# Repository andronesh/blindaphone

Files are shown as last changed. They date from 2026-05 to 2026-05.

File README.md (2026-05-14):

## ESP32-C3-Supermini wiring

| INMP441 | ESP32 |
| :-----: | :---: |
| GND |  GND  |
| VDD |  3v3  |
| SD | GPIO6 |
| LR |  GND  |
| WS | GPIO5 |
| SCK | GPIO4 |

| MAX98357A | ESP32 |
| :---: | :---: |
| LRC | GPIO5 |
| BCLK | GPIO4 |
| DIN | GPIO7 |
| GAIN | - |
| SD | - |
| GND |  GND  |
| VIN |  5v |

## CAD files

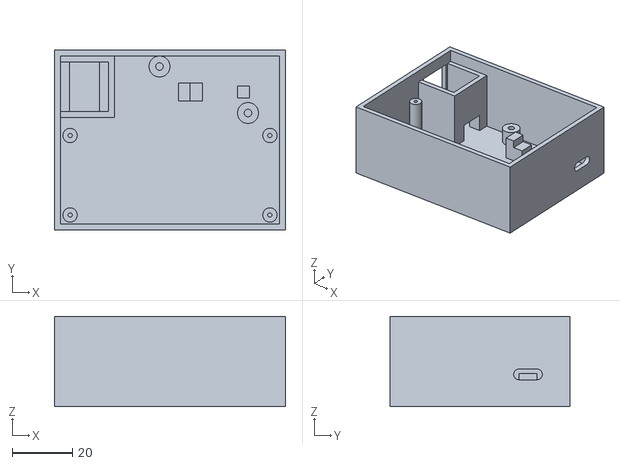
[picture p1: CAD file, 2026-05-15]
case_files/blindaphone box v2 bottom.stl
77.0 x 60.0 x 30.0

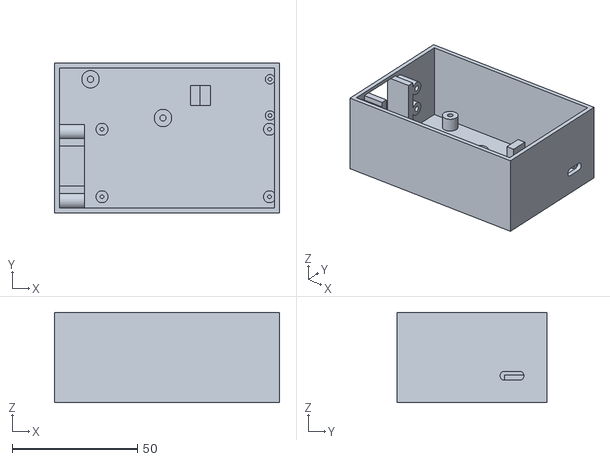
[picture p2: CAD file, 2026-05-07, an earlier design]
case_files/blindaphone box v1 bottom.stl
90.0 x 60.0 x 36.0

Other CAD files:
case_files/blindaphone box v1 bottom.f3d
case_files/blindaphone box v2 bottom.f3d

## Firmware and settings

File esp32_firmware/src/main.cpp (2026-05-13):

#include <Arduino.h>
#include "driver/i2s.h"
#include <math.h>
#include "Button.h"

#define I2S_PORT I2S_NUM_0

#define I2S_BCLK 4
#define I2S_LRCK 5
#define I2S_DIN  6   // mic
#define I2S_DOUT 7   // amp

const gpio_num_t REC_BTN_PIN = GPIO_NUM_9;

#define RX_PIN 20
#define TX_PIN 21
#define DIR_PIN 10
const gpio_num_t CMD_BTN_PIN = GPIO_NUM_3;

#define LED_PIN GPIO_NUM_2
bool isLedOn = false;

HardwareSerial RS485(1);

#define SAMPLE_RATE 16000
#define AUDIO_BLOCK_SAMPLES 128

volatile bool isTalking = false;
bool ignoreFirstPacket = true;

int32_t i2sInBuffer[AUDIO_BLOCK_SAMPLES];
int32_t i2sOutBuffer[AUDIO_BLOCK_SAMPLES];

int16_t uartBuffer[AUDIO_BLOCK_SAMPLES];

float GAIN = 15.0;

void setupI2S() {
    i2s_config_t config = {
        .mode = (i2s_mode_t)(I2S_MODE_MASTER | I2S_MODE_TX | I2S_MODE_RX),
        .sample_rate = SAMPLE_RATE,
        .bits_per_sample = I2S_BITS_PER_SAMPLE_32BIT,
        .channel_format = I2S_CHANNEL_FMT_ONLY_LEFT,
        .communication_format = I2S_COMM_FORMAT_I2S,
        .intr_alloc_flags = 0,
        .dma_buf_count = 8,
        .dma_buf_len = 128,
        .use_apll = false
    };

    i2s_pin_config_t pins = {
        .bck_io_num = I2S_BCLK,
        .ws_io_num = I2S_LRCK,
        .data_out_num = I2S_DOUT,
        .data_in_num = I2S_DIN
    };

    i2s_driver_install(I2S_PORT, &config, 0, NULL);
    i2s_set_pin(I2S_PORT, &pins);
}

void setTransmitMode() {
    digitalWrite(DIR_PIN, HIGH);
    // Serial.println("TX MODE");
    delayMicroseconds(50);
}

void setReceiveMode() {
    ignoreFirstPacket = true;
    delayMicroseconds(50);
    digitalWrite(DIR_PIN, LOW);
    // Serial.println("RX MODE");
    delayMicroseconds(50);
}

void sendMessage(const char* msg) {
    Serial.println("--- sending: " + String(msg));
    setTransmitMode();

    RS485.print(msg);
    RS485.flush();

    delayMicroseconds(10);
    setReceiveMode();
}

static void onCommandButtonPressDownCb(void *button_handle, void *usr_data) {
    Serial.println("--- CMD BTN DOWN ...");
    sendMessage("button pressed\n");
}

static void onRecordingButtonPressDownCb(void *button_handle, void *usr_data) {
    RS485.flush();

    while (RS485.available()) {
        RS485.read();
    }

    delay(20);

    setTransmitMode();
    isTalking = true;

    digitalWrite(LED_PIN, HIGH);
}

static void onRecordingButtonPressUpCb(void *button_handle, void *usr_data) {
    isTalking = false;

    RS485.flush();
    delay(20);
    setReceiveMode();

    while (RS485.available()) {
        RS485.read();
    }

    digitalWrite(LED_PIN, LOW);
}

void initButtons() {
    Button *btnCmd = new Button(CMD_BTN_PIN, false);
    btnCmd->attachPressDownEventCb(&onCommandButtonPressDownCb, NULL);

    Button *btnRec = new Button(REC_BTN_PIN, false);
    btnRec->attachPressDownEventCb(&onRecordingButtonPressDownCb, NULL);
    btnRec->attachPressUpEventCb(&onRecordingButtonPressUpCb, NULL);
}

void initRS485() {
    pinMode(DIR_PIN, OUTPUT);
    setReceiveMode();

    Serial.begin(115200);
    RS485.begin(1000000, SERIAL_8N1, RX_PIN, TX_PIN);

    RS485.setRxBufferSize(4096);
    RS485.setTxBufferSize(4096);
}

// void startRecordingSession() {
//     Serial.println("Recording...");
//     inRecordingSession = true;
//     recordedSamples = 0;
// }

// void processRecording() {
//     if (recordedSamples >= BUFFER_SAMPLES)
//         return;

//     int32_t rawSample;
//     size_t bytesRead;

//     i2s_read(I2S_PORT, &rawSample, sizeof(rawSample), &bytesRead, portMAX_DELAY);
//     rawSample >>= 8;
//     float x = rawSample / 8388608.0;
//     x *= GAIN;
//     x = x / (1.0 + fabs(x));

//     int32_t sample32 = (int32_t)(x * 2147483647);
//     audioBuffer[recordedSamples++] = sample32;
// }

// void stopAndPlayback() {
//     size_t bytesWritten;

//     for (size_t i = 0; i < recordedSamples; i++) {
//         i2s_write(I2S_PORT, &audioBuffer[i], sizeof(int32_t), &bytesWritten, portMAX_DELAY);
//     }

//     i2s_zero_dma_buffer(I2S_PORT);
//     i2s_stop(I2S_PORT);
//     delay(10);
//     i2s_start(I2S_PORT);

//     inPlaybackSession = false;
//     Serial.println("Done");
// }

void audioTask(void *param) {
    size_t bytesRead;
    size_t bytesWritten;

    while (true) {
        if (isTalking) {
            i2s_read(I2S_PORT, i2sInBuffer, sizeof(i2sInBuffer), &bytesRead, portMAX_DELAY);

            int samplesRead = bytesRead / sizeof(int32_t);

            // Convert 32-bit I2S -> 16-bit UART PCM
            for (int i = 0; i < samplesRead; i++) {
                int32_t raw = i2sInBuffer[i];
                raw >>= 8; // INMP441 style 24-bit alignment

                float x = raw / 8388608.0f;
                x *= GAIN;
                if (x > 0.8f) x = 0.8f;
                if (x < -0.8f) x = -0.8f;

                uartBuffer[i] = (int16_t)(x * 32767.0f);
            }

            RS485.write((uint8_t*)uartBuffer, samplesRead * sizeof(int16_t));
        } else {
            if (RS485.available() >= sizeof(uartBuffer)) {
                RS485.readBytes((char*)uartBuffer, sizeof(uartBuffer));

                if (ignoreFirstPacket) {
                    ignoreFirstPacket = false;
                    continue;
                }

                // Convert 16-bit UART PCM -> 32-bit I2S
                for (int i = 0; i < AUDIO_BLOCK_SAMPLES; i++) {
                    i2sOutBuffer[i] = ((int32_t)uartBuffer[i]) << 16;
                }

                i2s_write(I2S_PORT, i2sOutBuffer, sizeof(i2sOutBuffer), &bytesWritten, portMAX_DELAY);
            }
        }
    }
}

void setup() {
    pinMode(LED_PIN, OUTPUT);
    digitalWrite(LED_PIN, LOW);
    // Serial.begin(115200);

    setupI2S();
    initButtons();
    initRS485();
    xTaskCreatePinnedToCore(audioTask, "audioTask", 8192, NULL, 2, NULL, 0);
}

void loop() {
}

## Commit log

2026-05-07 feat: add 3D model and stl files for case
    [blindaphone box v1 bottom.f3d, blindaphone box v1 bottom.stl]
2026-05-10 feat: use async button lib to control recording/playback
2026-05-14 doc: add wiring info for INMP441 and MAX98357A
2026-05-15 feat: add files for new version of case (bottom)
    [blindaphone box v2 bottom.f3d, blindaphone box v2 bottom.stl]
